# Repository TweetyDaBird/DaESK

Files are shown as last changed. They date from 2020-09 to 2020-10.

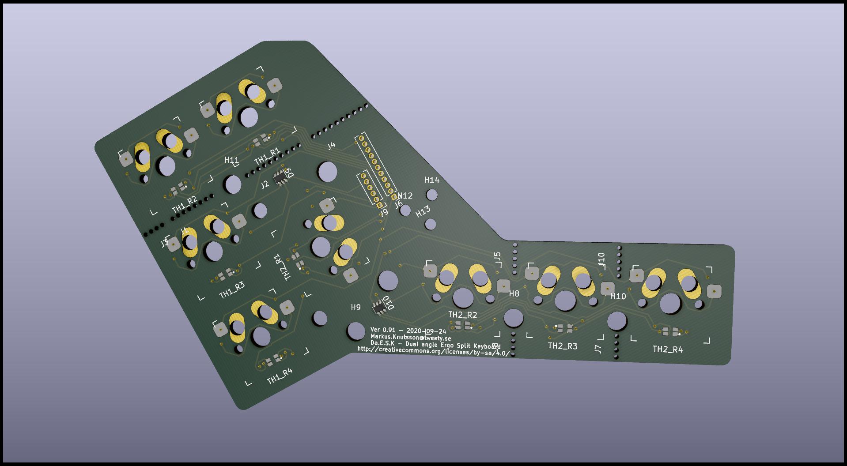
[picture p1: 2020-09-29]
3D/DaESK_TH1.jpg

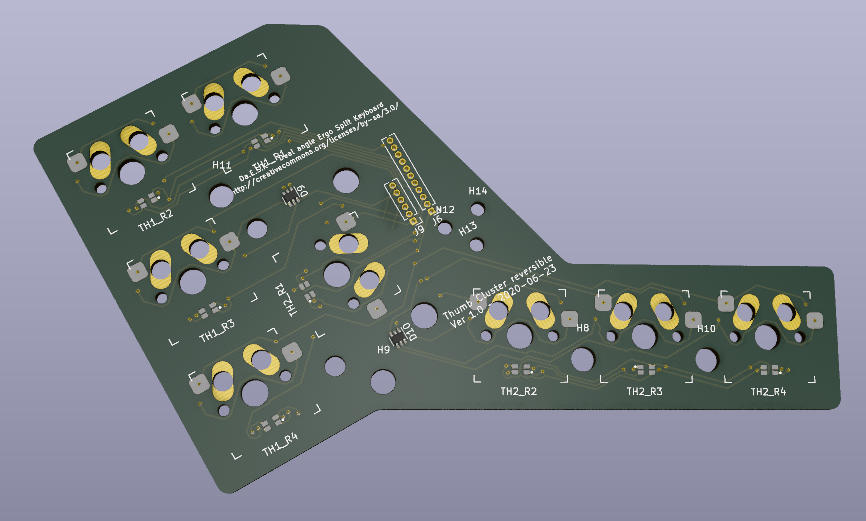
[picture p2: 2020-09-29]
3D/Thumb.png

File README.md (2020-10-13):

# DaESK - Dual axis Ergonomic Split Keyboard
 
 Copyright 2020 Markus Knutsson <markus.knutsson@tweety.se>
 
 Licensed under CERN-OHL-S v2 or any later version.

 DaESK is designed as an Ortholinear split keyboard with a detached thumb-key cluster, allowing a different angle/level of tent and positioning for the two parts.

 Key design features:
 * Full SMD design with onboard Atmega32u4 MCU compatible with QMK/TMK and other firmware suites.
 * Onboard IS31FL3737 RGB controller for full per-key adressable RGB matrix with built in effects.
 * Cherry MX type keyswitches in Kaihl Hot-Swap sockets.
 * Mid-mounted USB-C connector for durability and low profile.
 * Dual sided reversible design, identical PCB and thumbcluster PCB for both halves.
 * Each half can work as a master/slave pair (TRRS/I2C link) and as a one-hand gamepad without reprogramming.
 * Flexible thumbcluster design, supports 1-8 keys per side, connected to main PCB with ribbon cable.
 
 Available main layouts:
 * DaESK-4R a ~60%, 4-Row (4x6 key) layout with 48 keys plus 2-16 key thumbcluster for a total of 50-64 keys.
 * DaESK-3R a ~40%, 3-Row (3x6 key) layout with 36 keys plus 2-16 key thumbcluster for a total of 38-52 keys.
 
 Available Thumbcluster layouts:
 * DaESK-TH1 an adaptable ErgoDox style thumbcluster with break-away parts.
 
 Planned features:
 * Already designed in mounting holes for a low profile FR4 midplate/backplate case design.
 * Multiple thumbcluster designs.
 
 Current Version:
 v0.9x - Almost ready for prototype PCB order
 
 ToDo:
 * DaESK-3R, USB-C
 * BOM
 * Silkscreen

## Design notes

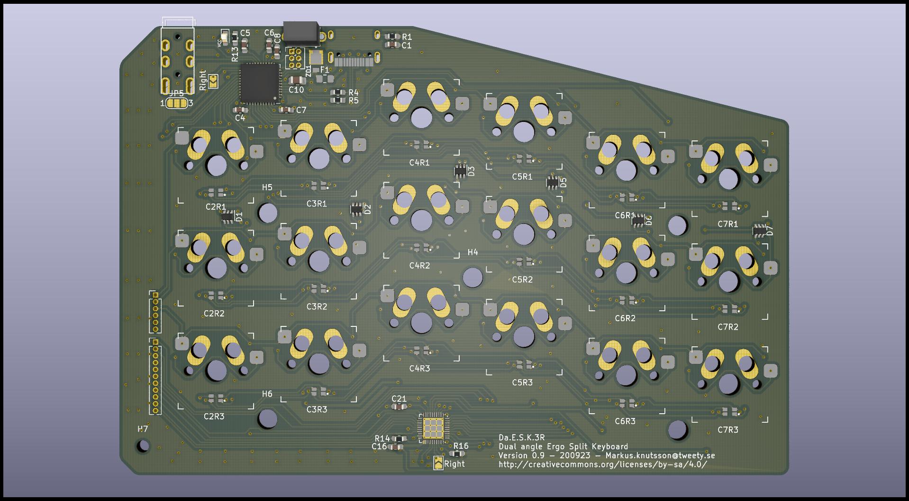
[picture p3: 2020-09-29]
3D/DaESK3R.jpg

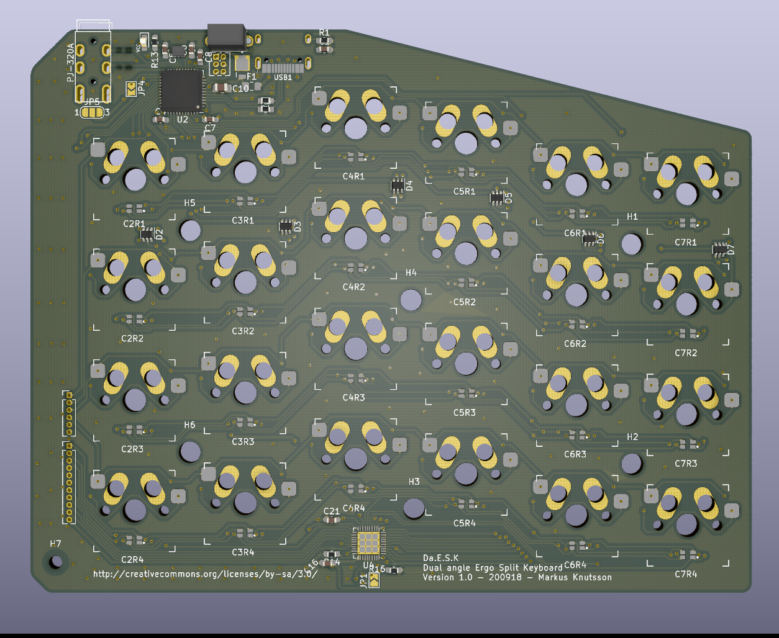
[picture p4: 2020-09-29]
3D/Keyboard3.png

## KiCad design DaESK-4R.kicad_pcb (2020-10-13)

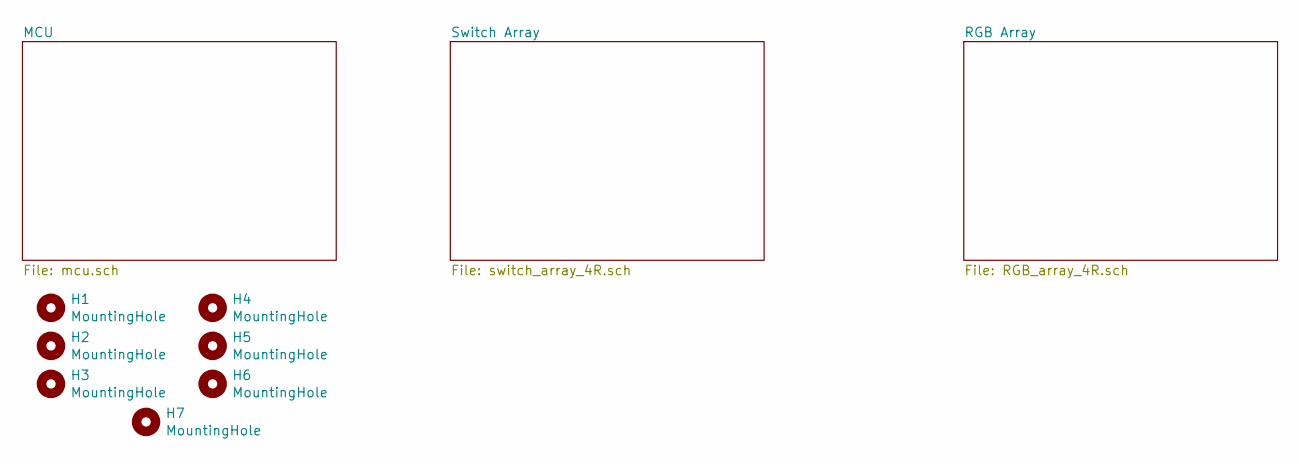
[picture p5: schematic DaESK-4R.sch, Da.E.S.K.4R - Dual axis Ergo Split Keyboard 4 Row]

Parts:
H1, H2, H3, H4, H5, H6: MountingHole; MountingHole_3.7mm; Manufacturer_Part_Number Hole
H7: MountingHole; MountingHole_2.2mm_M2; Manufacturer_Part_Number Hole

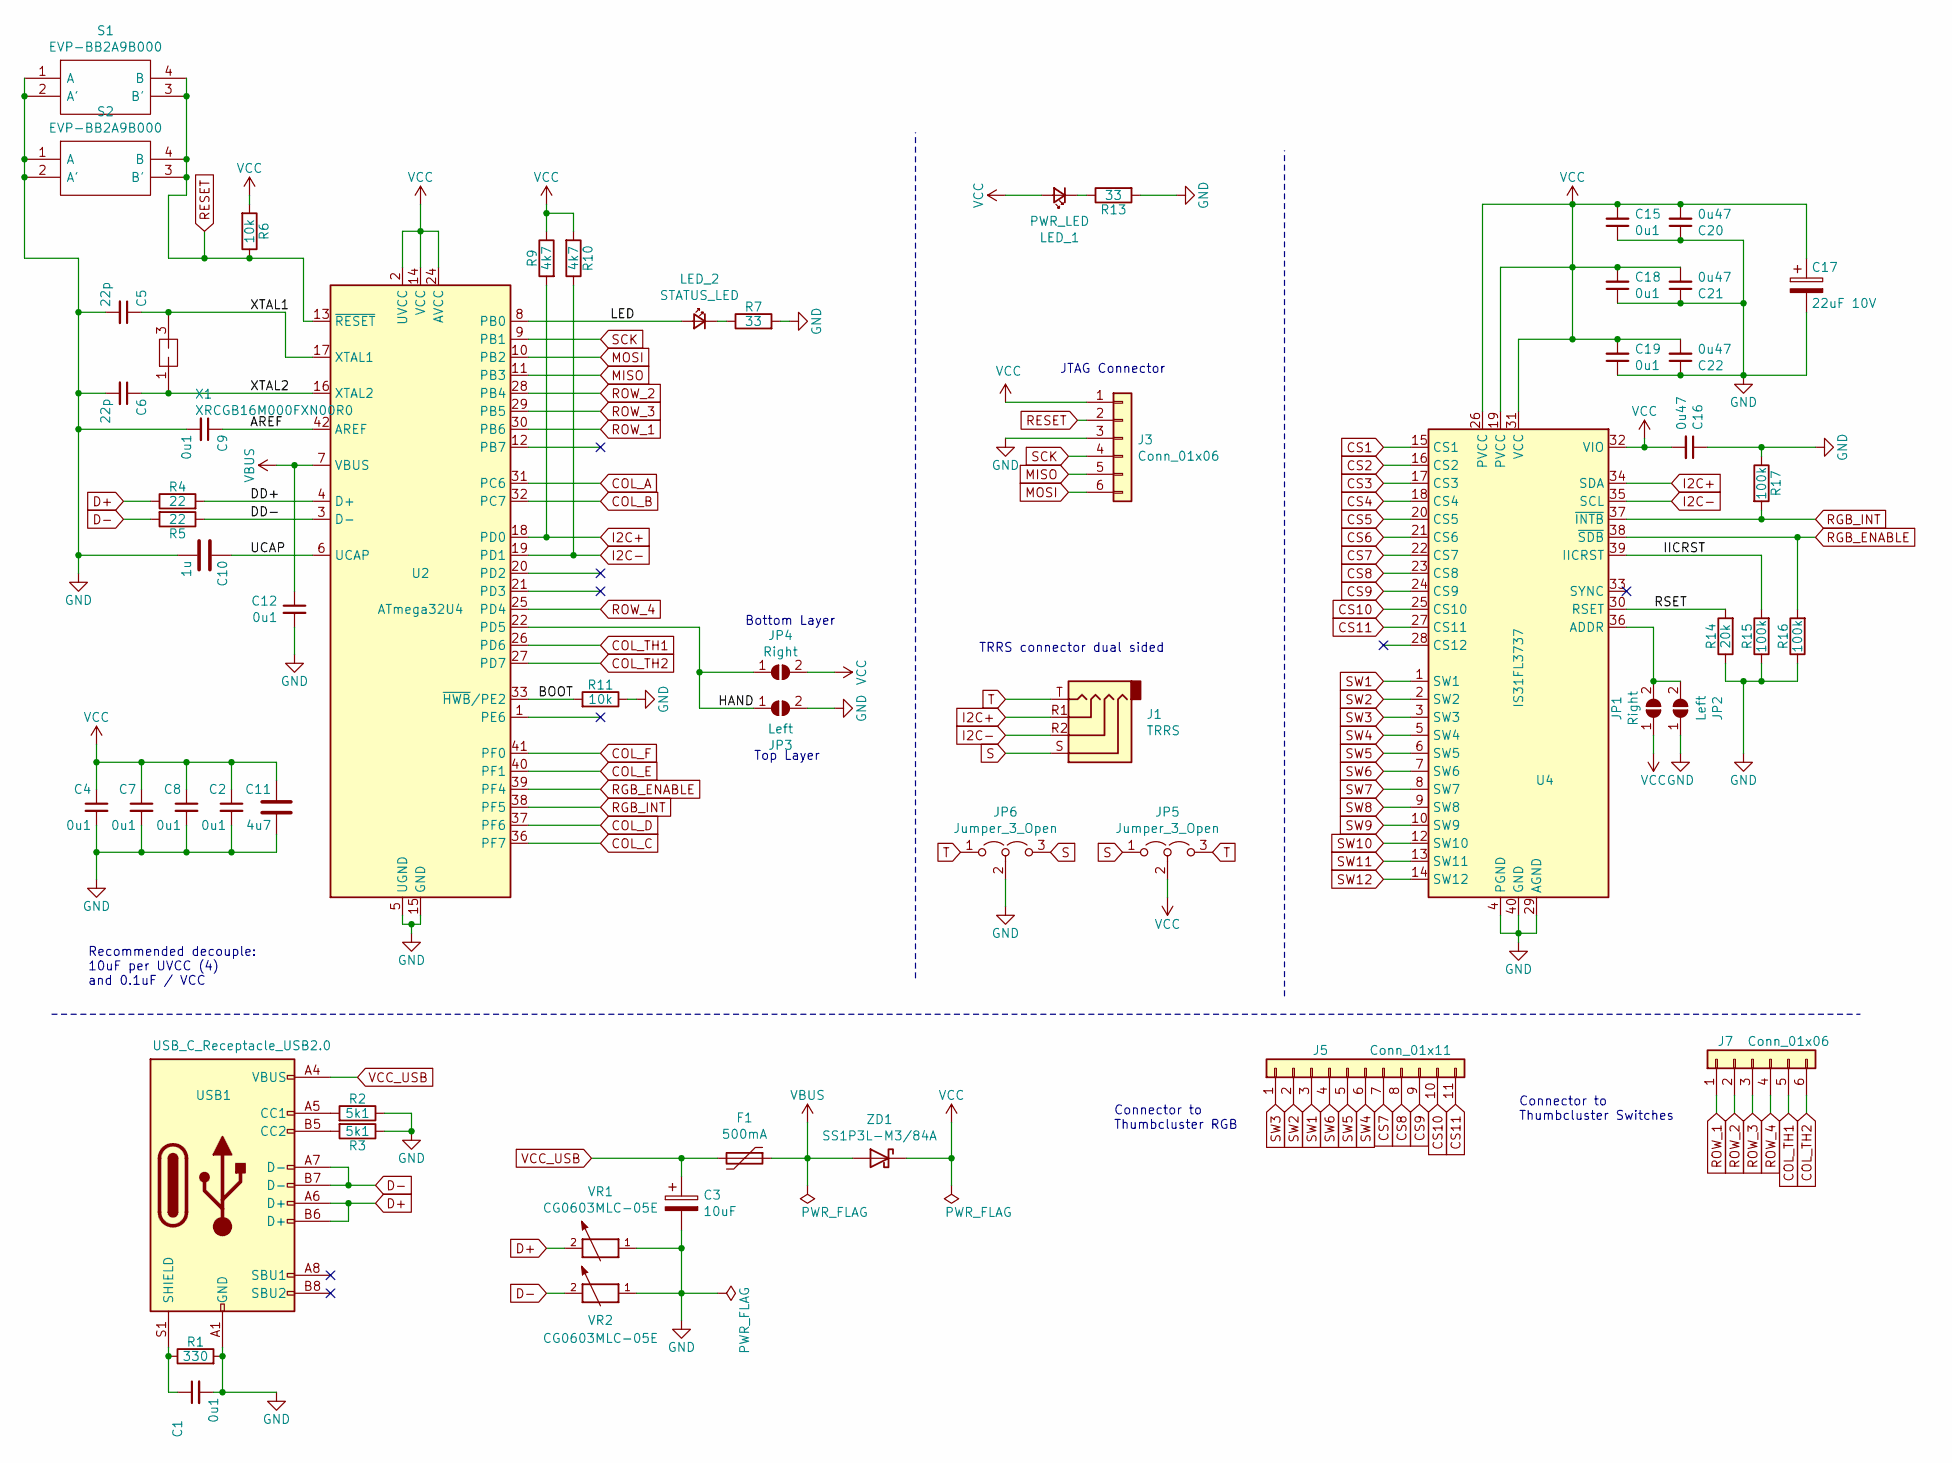
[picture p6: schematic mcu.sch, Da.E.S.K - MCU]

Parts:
C1, C2, C4, C7, C8, C9, C12, C15, C18, C19: 0u1; C_0603_1608Metric; Manufacturer_Part_Number 06035C104JAT2A; Mouser Part Number 581-06035C104JAT2A
C3: 10uF; CP_EIA-3216-18_Kemet-A; Manufacturer_Part_Number TAJA106M010RNJ; Mouser Part Number 581-TAJA106M010R
C5, C6: 22p; C_0603_1608Metric; Manufacturer_Part_Number 06035A220JAT2A; Mouser Part Number 581-06035A220J
C10: 1u; C_0805_2012Metric; Manufacturer_Part_Number CL21B105KBFNNNG; Mouser Part Number 187-CL21B105KBFNNNG
C11: 4u7; C_0805_2012Metric; Manufacturer_Part_Number C2012X7R1H475K125AC; Mouser Part Number 810-C2012X7R475K125C
C16, C20, C21, C22: 0u47; C_0603_1608Metric; Manufacturer_Part_Number UMK107B7474KA-TR; Mouser Part Number 963-UMK107B7474KA-TR
C17: 22uF 10V; CP_EIA-3216-18_Kemet-A; Manufacturer_Part_Number TPSA226K010T0900; Mouser Part Number 581-TPSA226K010T0900
F1: 500mA; Fuse_0603_1608Metric; Manufacturer_Part_Number 04000025WR; Mouser Part Number 576-04000025WR
J1: TRRS; TRRS-PJ-320A-reversible; Manufacturer_Part_Number PJ-320A
J3: Conn_01x06; PinHeader_2x03_P1.27mm_Vertical; Manufacturer_Part_Number Pinheader
J5: Conn_01x11; PinHeader_1x11_P1.27mm_Vertical; Manufacturer_Part_Number Pinheader
J7: Conn_01x06; PinHeader_1x06_P1.27mm_Vertical; Manufacturer_Part_Number Pinheader
JP1, JP4: Right; SolderJumper-2_P1.3mm_Open_TrianglePad1.0x1.5mm; Manufacturer_Part_Number Jumper
JP2, JP3: Left; SolderJumper-2_P1.3mm_Open_TrianglePad1.0x1.5mm; Manufacturer_Part_Number Jumper
JP5, JP6: Jumper_3_Open; SolderJumper-3_P1.3mm_Bridged12_RoundedPad1.0x1.5mm_NumberL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; Manufacturer_Part_Number Jumper
LED_1: PWR_LED; LED_0603_1608Metric; Manufacturer_Part_Number APT1608EC; Mouser Part Number 604-APT1608EC
LED_2: STATUS_LED; LED_0603_1608Metric; Manufacturer_Part_Number APT1608EC; Mouser Part Number 604-APT1608EC
R1: 330; R_0603_1608Metric; Manufacturer_Part_Number ERJ-3EKF3300V; Mouser Part Number 667-ERJ-3EKF3300V
R2, R3: 5k1; R_0603_1608Metric; Manufacturer_Part_Number ERJ-3EKF5101V; Mouser Part Number 667-ERJ-3EKF5101V
R4, R5: 22; R_0603_1608Metric; Manufacturer_Part_Number ERJ-3GEYJ220V; Mouser Part Number 667-ERJ-3GEYJ220V
R6, R11: 10k; R_0603_1608Metric; Manufacturer_Part_Number ERJ-3EKF1002V; Mouser Part Number 667-ERJ-3GEYJ103V
R7, R13: 33; R_0603_1608Metric; Manufacturer_Part_Number ERJ-3EKF33R0V; Mouser Part Number 667-ERJ-3EKF33R0V
R9, R10: 4k7; R_0603_1608Metric; Manufacturer_Part_Number ERJ-3GEYJ472V; Mouser Part Number 667-ERJ-3GEYJ472V
R14: 20k; R_0603_1608Metric; Manufacturer_Part_Number ERJ-3GEYJ203V; Mouser Part Number 667-ERJ-3GEYJ203V
R15, R16, R17: 100k; R_0603_1608Metric; Manufacturer_Part_Number ERJ-3EKF1003V; Mouser Part Number 667-ERJ-3EKF1003V
S1, S2: EVP-BB2A9B000; EVPBB2A9B000; Mouser Part Number 667-EVP-BB2A9B000
U2: ATmega32U4; QFN-44-1EP_7x7mm_P0.5mm_EP5.15x5.15mm_ThermalVias; Manufacturer_Part_Number ATMEGA32U4RC-MU; Mouser Part Number 556-ATMEGA32U4RC-MU
U4: IS31FL3737; QFN-40-1EP_5x5mm_P0.4mm_EP3.8x3.8mm_ThermalVias; Mouser Part Number 870-IS31FL3733-TQLS4
USB1: USB_C_Receptacle_USB2.0; HRO-TYPE-C-31-M-14; Manufacturer_Part_Number HRO-TYPE-C-31-M-14
VR1, VR2: CG0603MLC-05E; R_0603_1608Metric; Mouser Part Number 652-CG0603MLC-05E
X1: XRCGB16M000FXN00R0; XRCGB16M000FXN1R0; Mouser Part Number 81-XRCGB16M000FXN00R
ZD1: SS1P3L-M3/84A; 84A; Manufacturer_Part_Number SS1P3L-M3/84A; Mouser Part Number 625-SS1P3L-M3/84A

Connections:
/MCU/AREF: C9.1, U2.42 (AREF)
/MCU/BOOT: R11.2, U2.33 (~HWB~/PE2)
/MCU/DD+: R4.2, U2.4 (D+)
/MCU/DD-: R5.1, U2.3 (D-)
/MCU/HAND: JP3.1 (A), JP4.1 (A), U2.22 (PD5)
/MCU/IICRST: R15.2, U4.39 (IICRST)
/MCU/LED: LED_2.2 (A), U2.8 (PB0)
/MCU/RSET: R14.2, U4.30 (RSET)
/MCU/UCAP: C10.1, U2.6 (UCAP)
/MCU/XTAL1: C5.1, U2.17 (XTAL1), X1.3
/MCU/XTAL2: C6.1, U2.16 (XTAL2), X1.1
COL_A: U2.31 (PC6); also elsewhere on the board
COL_B: U2.32 (PC7); also elsewhere on the board
COL_C: U2.36 (PF7); also elsewhere on the board
COL_D: U2.37 (PF6); also elsewhere on the board
COL_E: U2.40 (PF1); also elsewhere on the board
COL_F: U2.41 (PF0); also elsewhere on the board
COL_TH1: J7.5, U2.26 (PD6)
COL_TH2: J7.6, U2.27 (PD7)
CS1: U4.15 (CS1); also elsewhere on the board
CS2: U4.16 (CS2); also elsewhere on the board
CS3: U4.17 (CS3); also elsewhere on the board
CS4: U4.18 (CS4); also elsewhere on the board
CS5: U4.20 (CS5); also elsewhere on the board
CS6: U4.21 (CS6); also elsewhere on the board
CS7: J5.7, U4.22 (CS7)
CS8: J5.8, U4.23 (CS8)
CS9: J5.9, U4.24 (CS9)
CS10: J5.10, U4.25 (CS10)
CS11: J5.11, U4.27 (CS11)
D+: R4.1, USB1.A6 (D+), USB1.B6 (D+), VR1.2
D-: R5.2, USB1.A7 (D-), USB1.B7 (D-), VR2.2
GND: C1.2, C2.2, C3.2, C4.2, C5.2, C6.2, C7.2, C8.2, C9.2, C10.2, C11.2, C12.2, C15.1, C16.1, C17.2, C18.1, C19.1, C20.1, C21.1, C22.1, J3.3, JP2.1 (A), JP3.2 (B), JP6.2 (C), R1.2, R2.1, R3.1, R7.2, R11.1, R13.2, R14.1, R15.1, R16.1, R17.1, S1.1 (A), S1.2 (A'), S2.1 (A), S2.2 (A'), U2.5 (UGND), U2.15 (GND), U2.23 (GND), U2.35 (GND), U2.43 (GND), U4.4 (PGND), U4.11 (PGND), U4.29 (AGND), U4.40 (GND), U4.41 (GND), USB1.A1 (GND), USB1.A12 (GND), USB1.B1 (GND), USB1.B12 (GND), VR1.1, VR2.1
I2C+: J1.R1, R9.2, U2.18 (PD0), U4.34 (SDA)
I2C-: J1.R2, R10.1, U2.19 (PD1), U4.35 (SCL)
MISO: J3.5, U2.11 (PB3)
MOSI: J3.6, U2.10 (PB2)
unnamed: C1.1, R1.1, USB1.S1 (SHIELD)
unnamed: JP1.2 (B), JP2.2 (B), U4.36 (ADDR)
unnamed: LED_1.1 (K), R13.1
unnamed: LED_2.1 (K), R7.1
unnamed: R2.2, USB1.A5 (CC1)
unnamed: R3.2, USB1.B5 (CC2)
RESET: J3.2, R6.1, S1.3 (B'), S1.4 (B), S2.3 (B'), S2.4 (B), U2.13 (~RESET)
RGB_ENABLE: R16.2, U2.39 (PF4), U4.38 (~SDB)
RGB_INT: R17.2, U2.38 (PF5), U4.37 (~INTB)
ROW_1: J7.1, U2.30 (PB6); also elsewhere on the board
ROW_2: J7.2, U2.28 (PB4); also elsewhere on the board
ROW_3: J7.3, U2.29 (PB5); also elsewhere on the board
ROW_4: J7.4, U2.25 (PD4); also elsewhere on the board
S: J1.S, JP5.1 (A), JP6.3 (B)
SCK: J3.4, U2.9 (PB1)
SW1: J5.3, U4.1 (SW1); also elsewhere on the board
SW2: J5.2, U4.2 (SW2); also elsewhere on the board
SW3: J5.1, U4.3 (SW3); also elsewhere on the board
SW4: J5.6, U4.5 (SW4); also elsewhere on the board
SW5: J5.5, U4.6 (SW5); also elsewhere on the board
SW6: J5.4, U4.7 (SW6); also elsewhere on the board
SW7: U4.8 (SW7); also elsewhere on the board
SW8: U4.9 (SW8); also elsewhere on the board
SW9: U4.10 (SW9); also elsewhere on the board
SW10: U4.12 (SW10); also elsewhere on the board
SW11: U4.13 (SW11); also elsewhere on the board
SW12: U4.14 (SW12); also elsewhere on the board
T: J1.T, JP5.3 (B), JP6.1 (A)
VBUS: C12.1, F1.1, U2.7 (VBUS), ZD1.2 (A)
VCC: C2.1, C4.1, C7.1, C8.1, C11.1, C15.2, C16.2, C17.1, C18.2, C19.2, C20.2, C21.2, C22.2, J3.1, JP1.1 (A), JP4.2 (B), JP5.2 (C), LED_1.2 (A), R6.2, R9.1, R10.2, U2.2 (UVCC), U2.14 (VCC), U2.24 (AVCC), U2.34 (VCC), U2.44 (AVCC), U4.19 (PVCC), U4.26 (PVCC), U4.31 (VCC), U4.32 (VIO), ZD1.1 (K)
VCC_USB: C3.1, F1.2, USB1.A4 (VBUS), USB1.A9 (VBUS), USB1.B4 (VBUS), USB1.B9 (VBUS)

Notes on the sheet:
Recommended decouple: 10uF per UVCC (4) and 0.1uF / VCC
JTAG Connector
Bottom Layer
Top Layer
TRRS connector dual sided
Connector to Thumbcluster Switches
Connector to Thumbcluster RGB

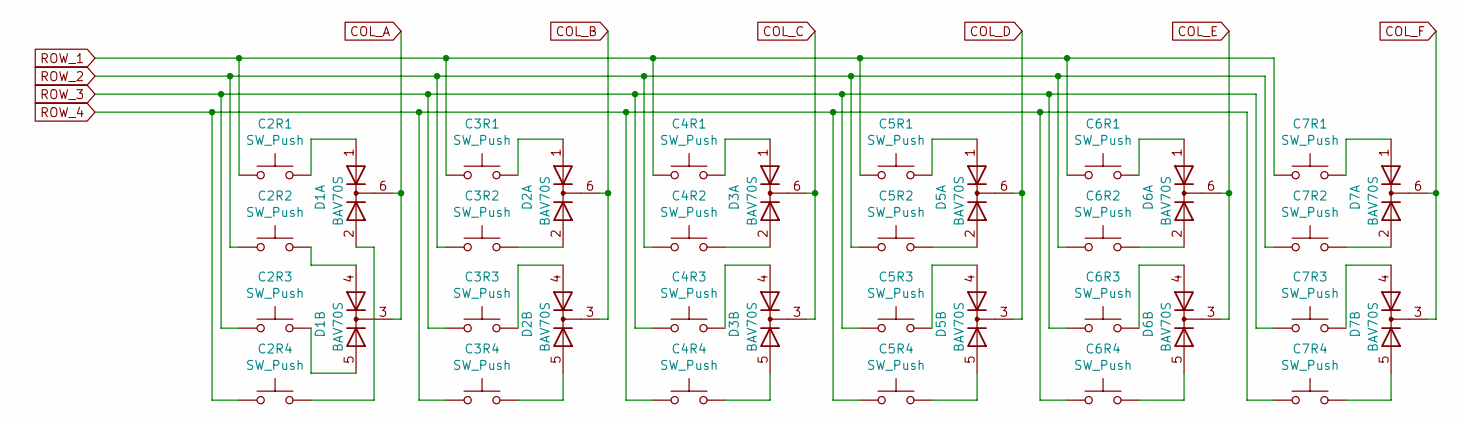
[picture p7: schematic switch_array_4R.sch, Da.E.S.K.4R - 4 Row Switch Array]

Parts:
C2R1, C2R2, C2R3, C2R4, C3R1, C3R2, C3R3, C3R4, C4R1, C4R2, C4R3, C4R4, C5R1, C5R2, C5R3, C5R4, C6R1, C6R2, C6R3, C6R4, C7R1, C7R2, C7R3, C7R4: SW_Push; Kailh_socket_MX_reversible_v2; Manufacturer_Part_Number CPG151101S11
D1, D2, D3, D5, D6, D7: BAV70S; SOT-363_SC-70-6; Manufacturer_Part_Number BAV70S,135; Mouser Part Number 771-BAV70S135

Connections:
COL_A: D1.3 (K), D1.6 (K); also elsewhere on the board
COL_B: D2.3 (K), D2.6 (K); also elsewhere on the board
COL_C: D3.3 (K), D3.6 (K); also elsewhere on the board
COL_D: D5.3 (K), D5.6 (K); also elsewhere on the board
COL_E: D6.3 (K), D6.6 (K); also elsewhere on the board
COL_F: D7.3 (K), D7.6 (K); also elsewhere on the board
unnamed: C2R1.2, D1.1 (A)
unnamed: C2R2.2, D1.4 (A)
unnamed: C2R3.2, D1.5 (A)
unnamed: C2R4.2, D1.2 (A)
unnamed: C3R1.2, D2.1 (A)
unnamed: C3R2.2, D2.2 (A)
unnamed: C3R3.2, D2.4 (A)
unnamed: C3R4.2, D2.5 (A)
unnamed: C4R1.2, D3.1 (A)
unnamed: C4R2.2, D3.2 (A)
unnamed: C4R3.2, D3.4 (A)
unnamed: C4R4.2, D3.5 (A)
unnamed: C5R1.2, D5.1 (A)
unnamed: C5R2.2, D5.2 (A)
unnamed: C5R3.2, D5.4 (A)
unnamed: C5R4.2, D5.5 (A)
unnamed: C6R1.2, D6.1 (A)
unnamed: C6R2.2, D6.2 (A)
unnamed: C6R3.2, D6.4 (A)
unnamed: C6R4.2, D6.5 (A)
unnamed: C7R1.2, D7.1 (A)
unnamed: C7R2.2, D7.2 (A)
unnamed: C7R3.2, D7.4 (A)
unnamed: C7R4.2, D7.5 (A)
ROW_1: C2R1.1, C3R1.1, C4R1.1, C5R1.1, C6R1.1, C7R1.1; also elsewhere on the board
ROW_2: C2R2.1, C3R2.1, C4R2.1, C5R2.1, C6R2.1, C7R2.1; also elsewhere on the board
ROW_3: C2R3.1, C3R3.1, C4R3.1, C5R3.1, C6R3.1, C7R3.1; also elsewhere on the board
ROW_4: C2R4.1, C3R4.1, C4R4.1, C5R4.1, C6R4.1, C7R4.1; also elsewhere on the board

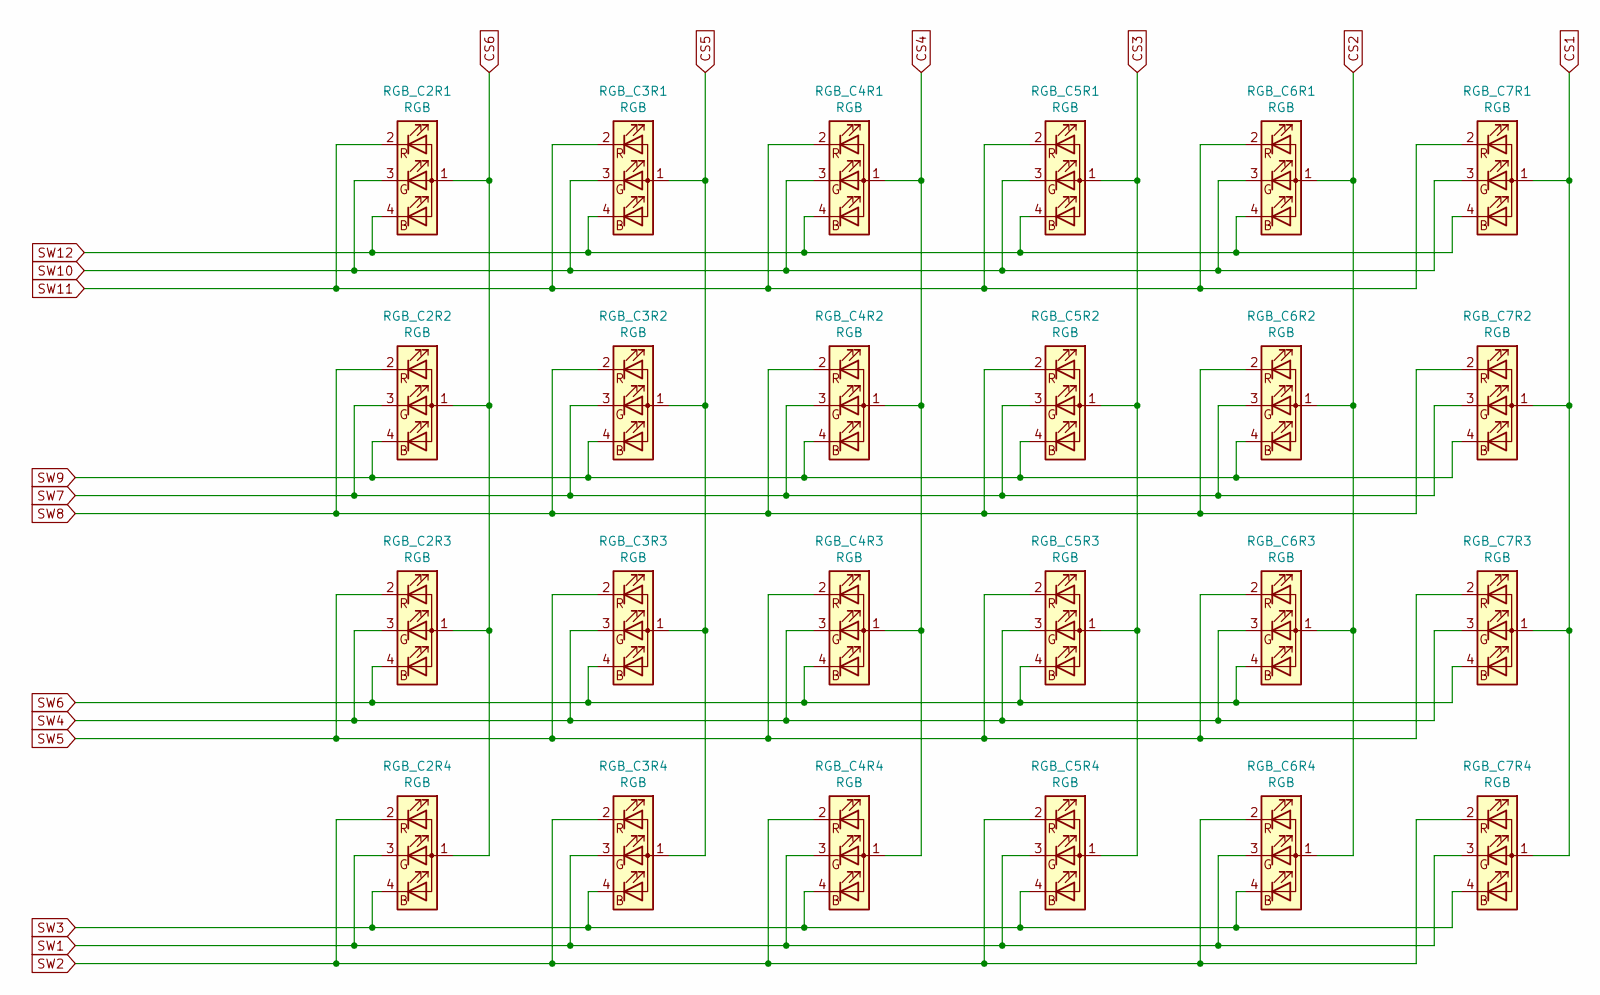
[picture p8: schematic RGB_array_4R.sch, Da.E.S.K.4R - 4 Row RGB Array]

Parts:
RGB_C2R1, RGB_C2R2, RGB_C2R3, RGB_C2R4, RGB_C3R1, RGB_C3R2, RGB_C3R3, RGB_C3R4, RGB_C4R1, RGB_C4R2, RGB_C4R3, RGB_C4R4, RGB_C5R1, RGB_C5R2, RGB_C5R3, RGB_C5R4, RGB_C6R1, RGB_C6R2, RGB_C6R3, RGB_C6R4, RGB_C7R1, RGB_C7R2, RGB_C7R3, RGB_C7R4: RGB; LEDSC160X160X070-4N_reversible; Mouser Part Number 604-APTF1616SEJ3ZGGV

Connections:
CS1: RGB_C7R1.1 (A), RGB_C7R2.1 (A), RGB_C7R3.1 (A), RGB_C7R4.1 (A); also elsewhere on the board
CS2: RGB_C6R1.1 (A), RGB_C6R2.1 (A), RGB_C6R3.1 (A), RGB_C6R4.1 (A); also elsewhere on the board
CS3: RGB_C5R1.1 (A), RGB_C5R2.1 (A), RGB_C5R3.1 (A), RGB_C5R4.1 (A); also elsewhere on the board
CS4: RGB_C4R1.1 (A), RGB_C4R2.1 (A), RGB_C4R3.1 (A), RGB_C4R4.1 (A); also elsewhere on the board
CS5: RGB_C3R1.1 (A), RGB_C3R2.1 (A), RGB_C3R3.1 (A), RGB_C3R4.1 (A); also elsewhere on the board
CS6: RGB_C2R1.1 (A), RGB_C2R2.1 (A), RGB_C2R3.1 (A), RGB_C2R4.1 (A); also elsewhere on the board
SW1: RGB_C2R4.3 (GK), RGB_C3R4.3 (GK), RGB_C4R4.3 (GK), RGB_C5R4.3 (GK), RGB_C6R4.3 (GK), RGB_C7R4.3 (GK); also elsewhere on the board
SW2: RGB_C2R4.2 (RK), RGB_C3R4.2 (RK), RGB_C4R4.2 (RK), RGB_C5R4.2 (RK), RGB_C6R4.2 (RK), RGB_C7R4.2 (RK); also elsewhere on the board
SW3: RGB_C2R4.4 (BK), RGB_C3R4.4 (BK), RGB_C4R4.4 (BK), RGB_C5R4.4 (BK), RGB_C6R4.4 (BK), RGB_C7R4.4 (BK); also elsewhere on the board
SW4: RGB_C2R3.3 (GK), RGB_C3R3.3 (GK), RGB_C4R3.3 (GK), RGB_C5R3.3 (GK), RGB_C6R3.3 (GK), RGB_C7R3.3 (GK); also elsewhere on the board
SW5: RGB_C2R3.2 (RK), RGB_C3R3.2 (RK), RGB_C4R3.2 (RK), RGB_C5R3.2 (RK), RGB_C6R3.2 (RK), RGB_C7R3.2 (RK); also elsewhere on the board
SW6: RGB_C2R3.4 (BK), RGB_C3R3.4 (BK), RGB_C4R3.4 (BK), RGB_C5R3.4 (BK), RGB_C6R3.4 (BK), RGB_C7R3.4 (BK); also elsewhere on the board
SW7: RGB_C2R2.3 (GK), RGB_C3R2.3 (GK), RGB_C4R2.3 (GK), RGB_C5R2.3 (GK), RGB_C6R2.3 (GK), RGB_C7R2.3 (GK); also elsewhere on the board
SW8: RGB_C2R2.2 (RK), RGB_C3R2.2 (RK), RGB_C4R2.2 (RK), RGB_C5R2.2 (RK), RGB_C6R2.2 (RK), RGB_C7R2.2 (RK); also elsewhere on the board
SW9: RGB_C2R2.4 (BK), RGB_C3R2.4 (BK), RGB_C4R2.4 (BK), RGB_C5R2.4 (BK), RGB_C6R2.4 (BK), RGB_C7R2.4 (BK); also elsewhere on the board
SW10: RGB_C2R1.3 (GK), RGB_C3R1.3 (GK), RGB_C4R1.3 (GK), RGB_C5R1.3 (GK), RGB_C6R1.3 (GK), RGB_C7R1.3 (GK); also elsewhere on the board
SW11: RGB_C2R1.2 (RK), RGB_C3R1.2 (RK), RGB_C4R1.2 (RK), RGB_C5R1.2 (RK), RGB_C6R1.2 (RK), RGB_C7R1.2 (RK); also elsewhere on the board
SW12: RGB_C2R1.4 (BK), RGB_C3R1.4 (BK), RGB_C4R1.4 (BK), RGB_C5R1.4 (BK), RGB_C6R1.4 (BK), RGB_C7R1.4 (BK); also elsewhere on the board

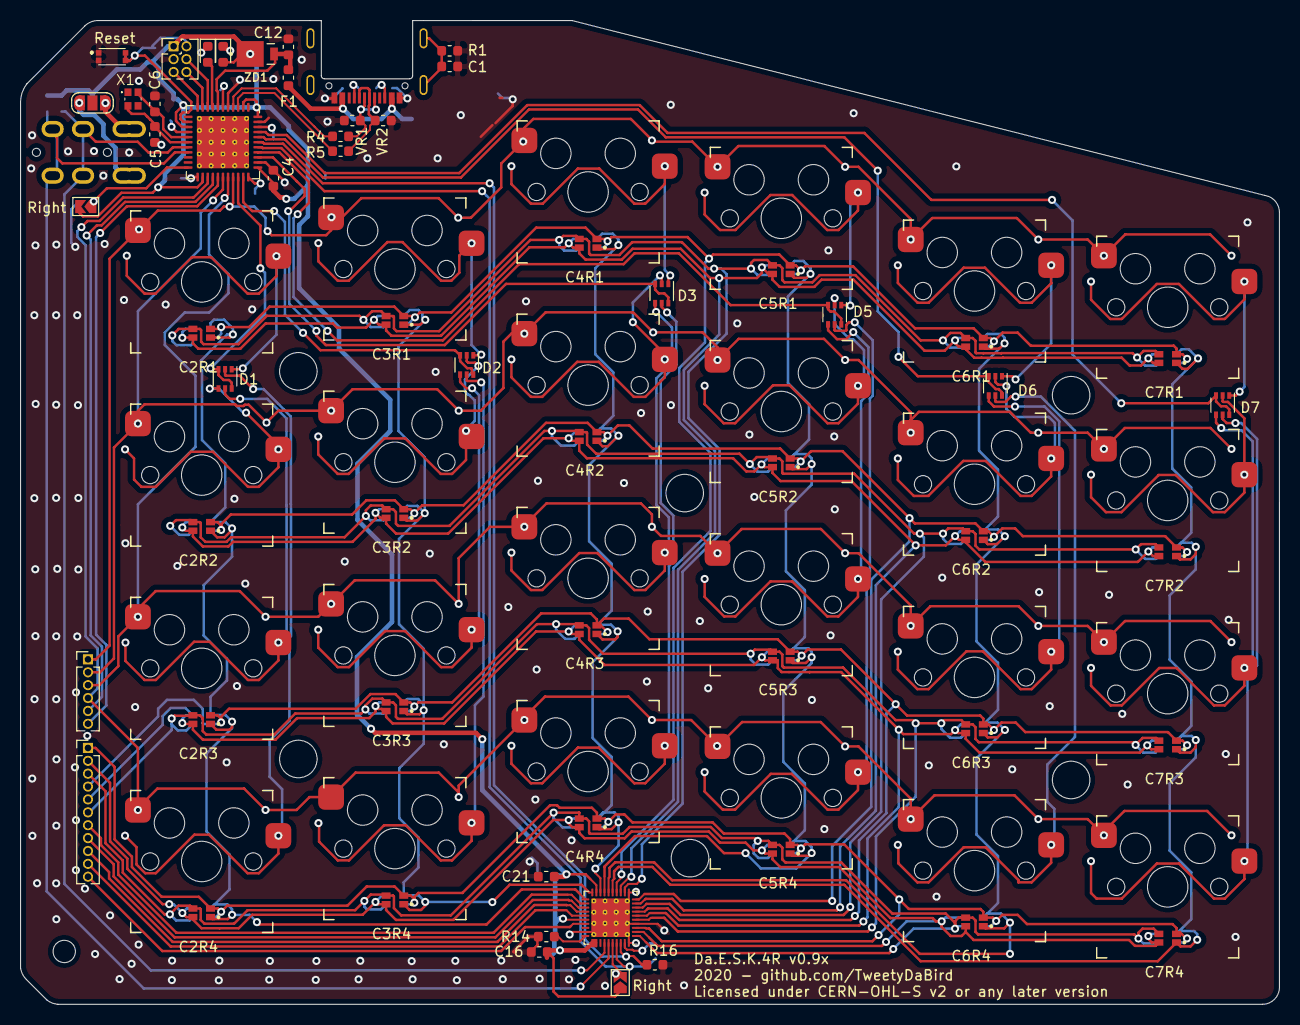
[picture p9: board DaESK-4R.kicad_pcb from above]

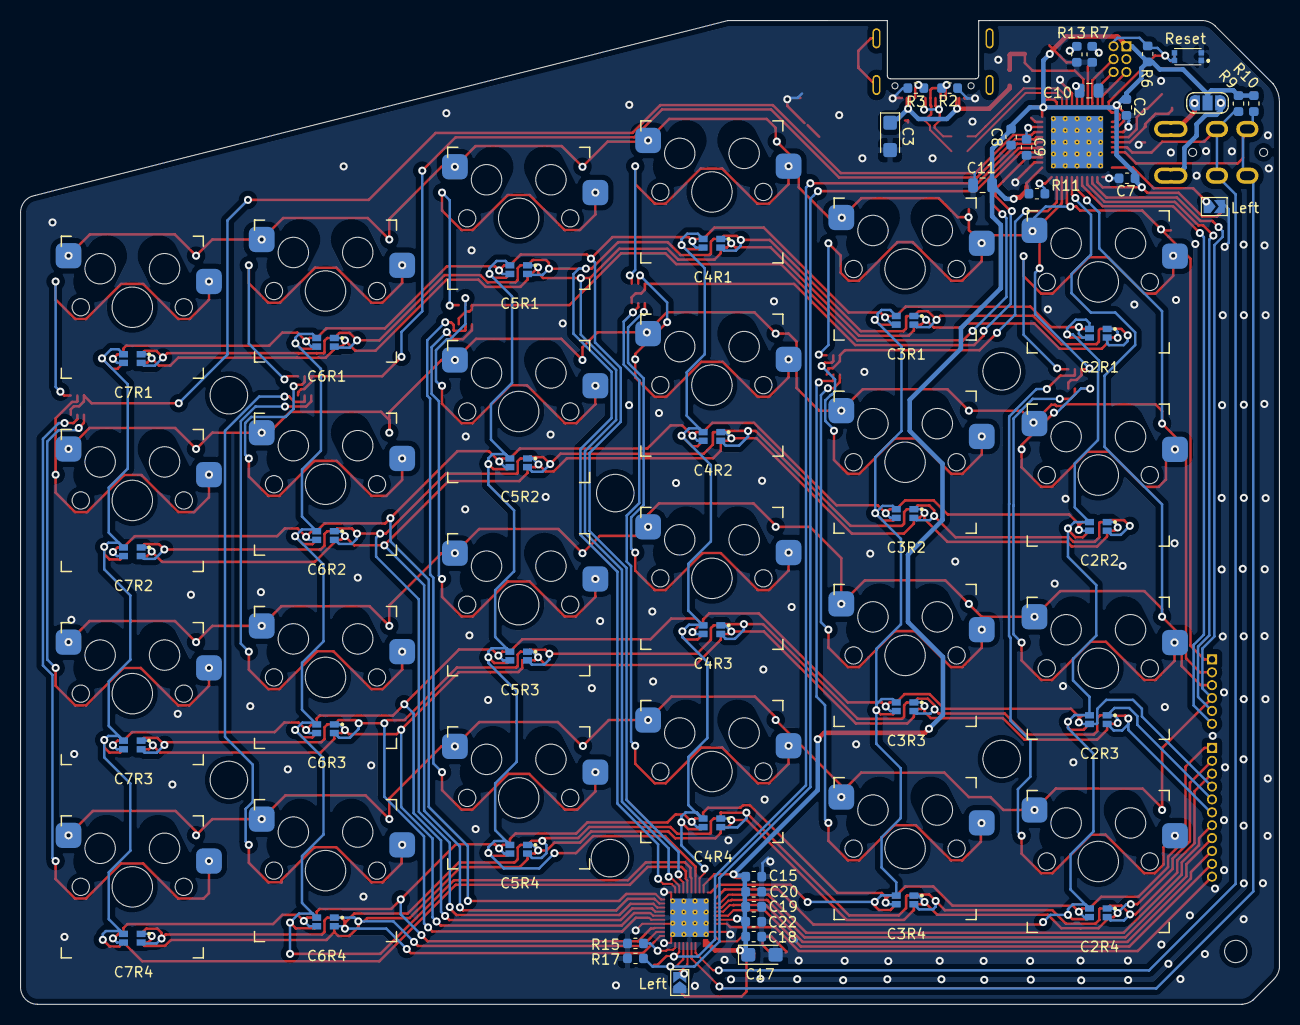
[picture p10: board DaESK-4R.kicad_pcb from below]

Board: 2 copper layers, 124.1 x 97.0 mm, 118 parts (27 on the bottom side), 92 nets.

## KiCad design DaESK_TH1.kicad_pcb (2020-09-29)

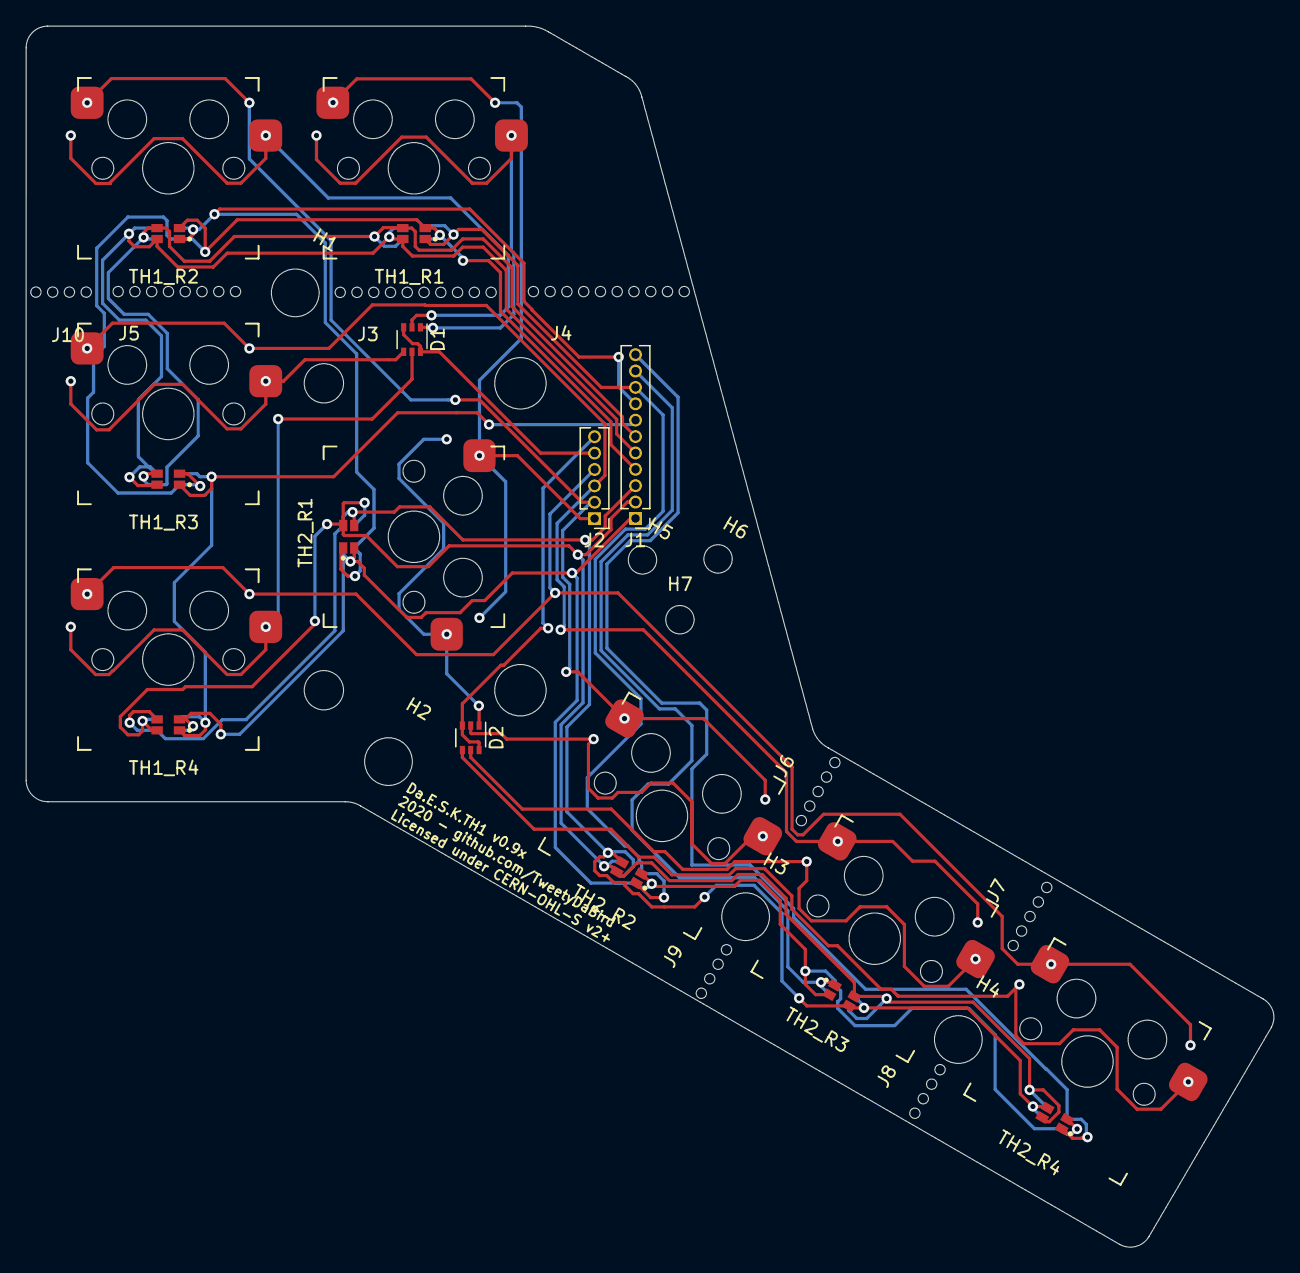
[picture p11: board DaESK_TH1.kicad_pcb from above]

Board: 2 copper layers, 96.8 x 94.7 mm, 36 parts (0 on the bottom side), 25 nets.

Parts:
D1, D2: BAV70S; SOT-363_SC-70-6
H1, H2, H3, H4: MountingHole; MountingHole_3.7mm
H5, H6, H7: MountingHole; MountingHole_2.2mm_M2_ISO7380
J1: Conn_01x11; PinHeader_1x11_P1.27mm_Vertical
J2: Conn_01x06; PinHeader_1x06_P1.27mm_Vertical
J3, J4: Mousebite 10; mousebite10
J5: Mousebite 8; mousebite8
J6, J7: Mousebite 5; mousebite5
J8, J9, J10: Mousebite 4; mousebite4
RGB_TH1R1: CB1_9; LEDSC160X160X070-4N_reversible
RGB_TH1R2: CB1_8; LEDSC160X160X070-4N_reversible
RGB_TH1R3: CB1_7; LEDSC160X160X070-4N_reversible
RGB_TH1R4: CB1_6; LEDSC160X160X070-4N_reversible
RGB_TH2R1: CB2_1; LEDSC160X160X070-4N_reversible
RGB_TH2R2: CB2_2; LEDSC160X160X070-4N_reversible
RGB_TH2R3, RGB_TH2R4: CB2_3; LEDSC160X160X070-4N_reversible
ST1: stab; Stabilizer_MX_2u
TH1_R1, TH1_R2, TH1_R3, TH1_R4, TH2_R2, TH2_R3, TH2_R4: SW_Push; Kailh_socket_MX_reversible_v2
TH2_R1: SW_Push; Kailh_socket_MX_reversible_v2_2u

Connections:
CS1_TH: J1.7, RGB_TH1R3.1, RGB_TH1R4.1
CS2_TH: J1.8, RGB_TH1R2.1, RGB_TH2R1.1
CS3_TH: J1.9, RGB_TH1R1.1, RGB_TH2R2.1
CS4_TH: J1.10, RGB_TH2R3.1
CS5_TH: J1.11, RGB_TH2R4.1
unnamed: D1.1, TH1_R1.2
unnamed: D1.2, TH1_R2.2
unnamed: D1.4, TH1_R3.2
unnamed: D1.5, TH1_R4.2
unnamed: D2.1, TH2_R1.2
unnamed: D2.2, TH2_R2.2
unnamed: D2.4, TH2_R4.2
unnamed: D2.5, TH2_R3.2
SW1_TH: J1.3, RGB_TH1R4.3, RGB_TH2R1.3, RGB_TH2R2.3, RGB_TH2R3.3, RGB_TH2R4.3
SW2_TH: J1.2, RGB_TH1R4.2, RGB_TH2R1.2, RGB_TH2R2.2, RGB_TH2R3.2, RGB_TH2R4.2
SW3_TH: J1.1, RGB_TH1R4.4, RGB_TH2R1.4, RGB_TH2R2.4, RGB_TH2R3.4, RGB_TH2R4.4
SW4_TH: J1.6, RGB_TH1R1.3, RGB_TH1R2.3, RGB_TH1R3.3
SW5_TH: J1.5, RGB_TH1R1.2, RGB_TH1R2.2, RGB_TH1R3.2
SW6_TH: J1.4, RGB_TH1R1.4, RGB_TH1R2.4, RGB_TH1R3.4
TH_COL_TH1: D1.3, D1.6, J2.5
TH_COL_TH2: D2.3, D2.6, J2.6
TH_ROW_1: J2.1, TH1_R1.1, TH2_R1.1
TH_ROW_2: J2.2, TH1_R2.1, TH2_R2.1
TH_ROW_3: J2.3, TH1_R3.1, TH2_R3.1
TH_ROW_4: J2.4, TH1_R4.1, TH2_R4.1

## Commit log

2020-09-29 initial upload of design
    [DaESK-3R.kicad_pcb, DaESK-3R.sch, DaESK-4R.kicad_pcb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]
2020-09-29 pcb udated
    [DaESK_TH1.kicad_pcb, thumb_1.sch]
2020-10-13 4R updated placement of MCU
    [DaESK-4R.kicad_pcb, DaESK-4R.sch, RGB_array_4R.sch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]
2020-10-13 fixed reset switch
    [DaESK-4R.kicad_pcb, mcu.sch]
